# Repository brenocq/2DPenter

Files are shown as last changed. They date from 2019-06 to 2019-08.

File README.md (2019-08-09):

# 2D Penter
_by Breno Queiroz and Dikson Ferreira_

<p align="center">
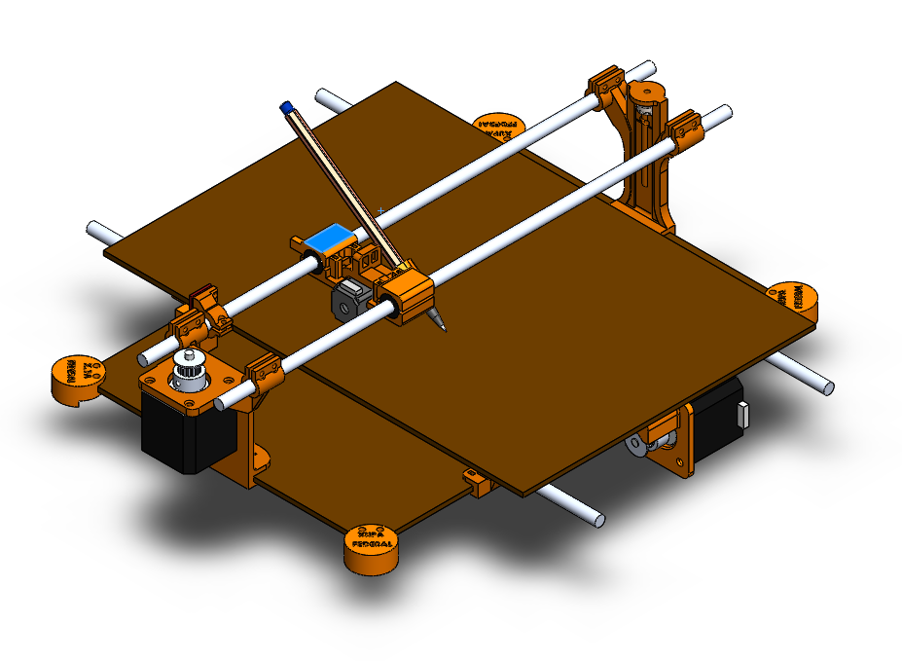
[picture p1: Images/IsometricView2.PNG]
 
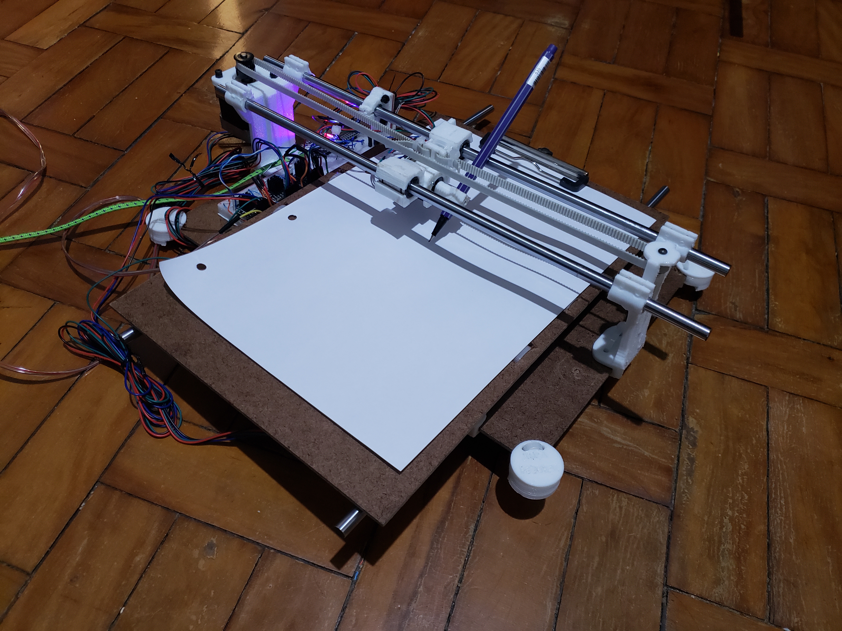
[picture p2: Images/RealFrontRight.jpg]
 
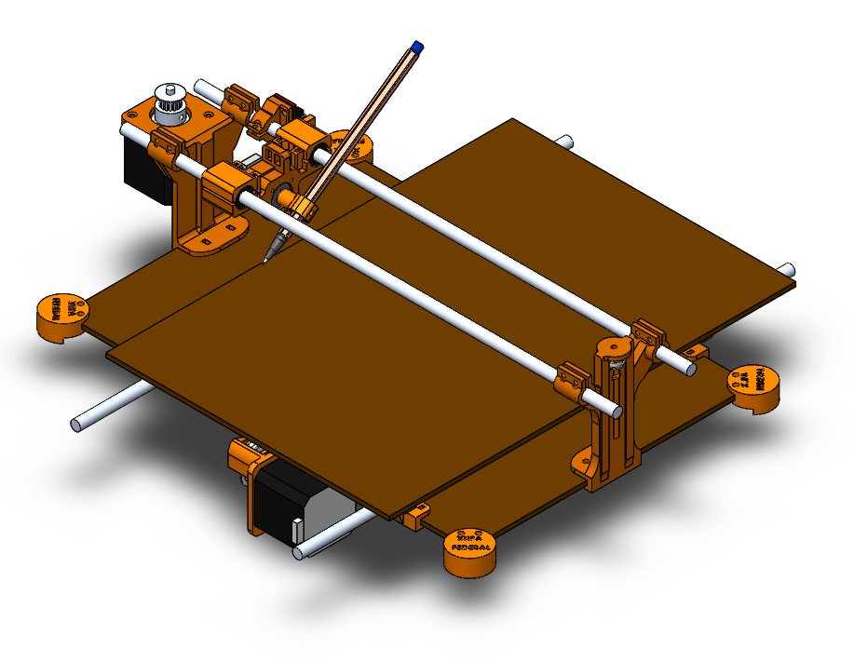
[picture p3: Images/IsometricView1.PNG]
 
</p>

## Introduction
This printer was designed to draw polynomial functions from a string. When connecting to the wifi network created by ESP32, it is possible to make the printer go home, move the axes, draw points on the paper, or send the polynomial function string to draw the graphic.

## Materials used
 - (2) Nema17 stepper motors
 - (1) Nema8 stepper motor
 - (3) Stepper Motor Driver
 - (2) GT2 Pulley 20T
 - (1) Esp32 DOIT
 - (2) Mechanical Endstop
 - (2) Clipboards
 - (1) GT2 Belt 6mm 3 meters
 - (1) PLA filament 0.25kg
 - (1) Stabilo Pen (can be another one of the same size)
 - (6) LM8UU bearing
 - (8) F623ZZ flange

## Building
All 3d modeled parts are available in the `3Dmodels` folder. First, open the `2Dprinter_v0.SLDASM` file using SolidWorks. After that, generate the STL file of each assembly part. Printed parts must have at least 50% of infill to ensure a sturdy structure.

#### Pen structure
<p align="center">
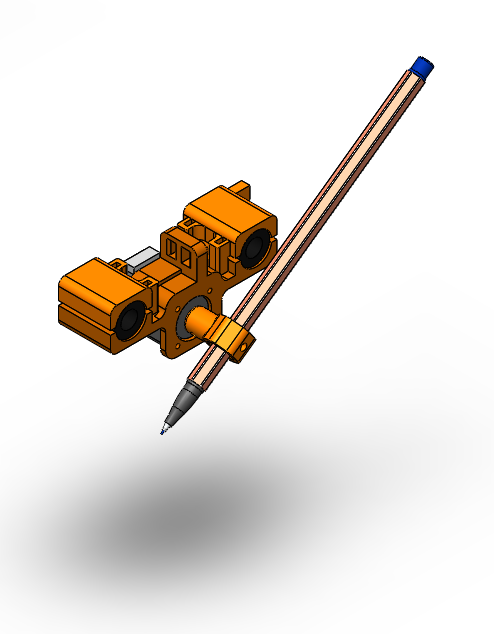
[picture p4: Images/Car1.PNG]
 
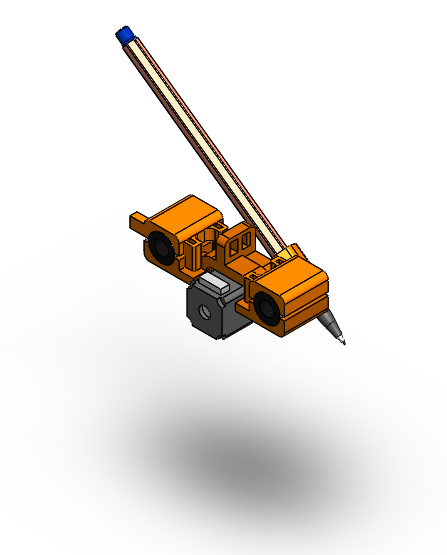
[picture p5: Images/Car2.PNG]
 
</p>

A Nema8 stepper motor was used to move the pen up and down.

#### Motor X
<p align="center">
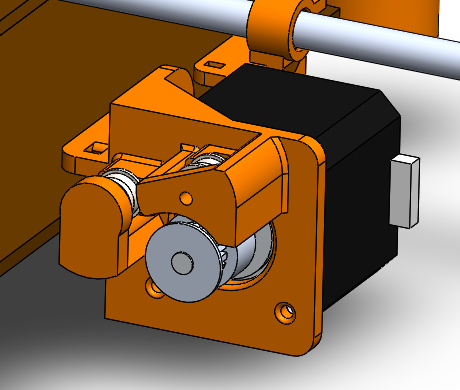
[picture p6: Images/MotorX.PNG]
 
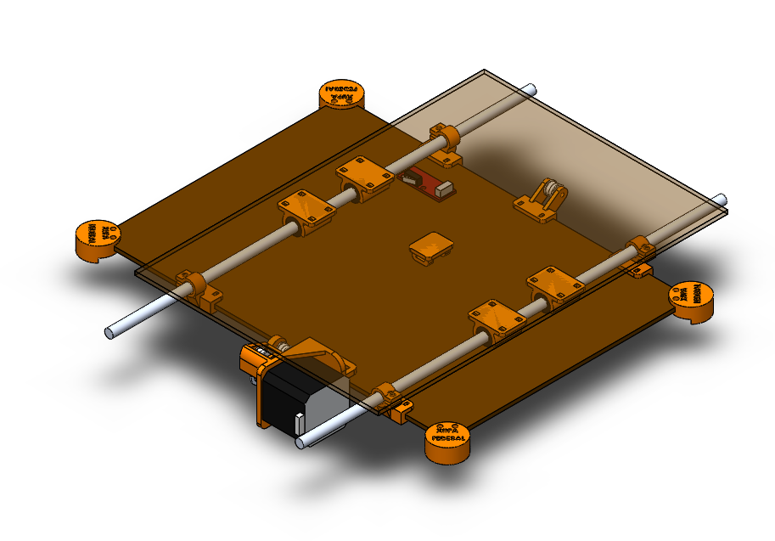
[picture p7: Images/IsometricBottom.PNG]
 
</p>

The image on the left shows motor X, this motor moves the bed to the left and right. There are 4 LM8UU bearing on the bottom of the bed as shown in the image on the right. An endstop button was used to set the minimum X.

#### Motor Y
<p align="center">
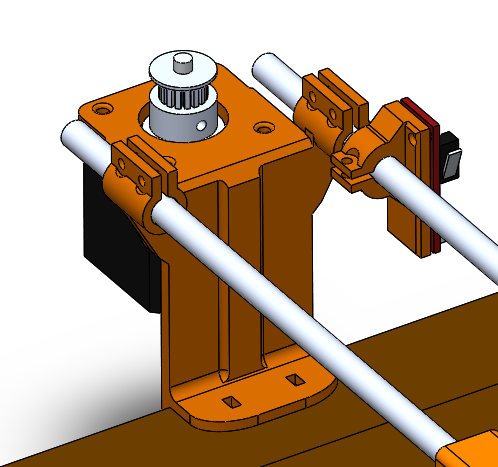
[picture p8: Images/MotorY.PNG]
  
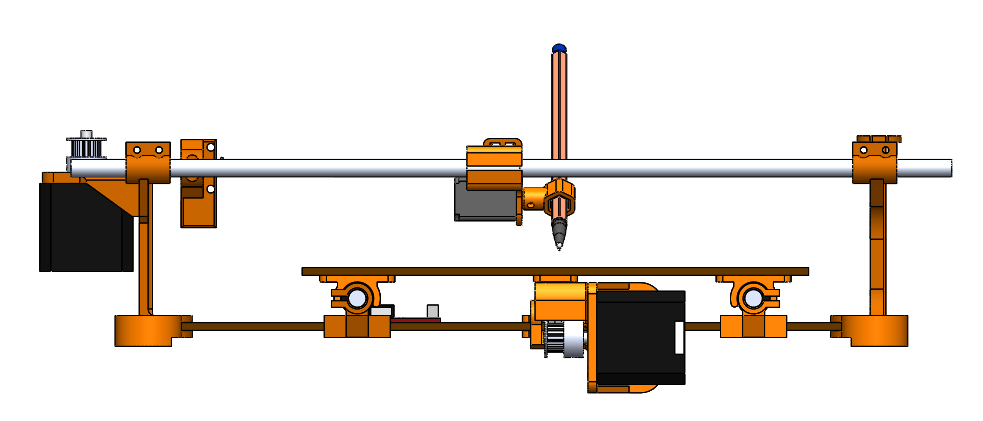
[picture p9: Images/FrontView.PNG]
  
</p>

The image above shows the motor Y, this motor moves the pen up and down. There is also an endstop button on the Y axis to detect the minimum Y.

#### Electronic
TODO

## How to use
Before going on, you must have Atom installed on your computer with the PlatformIO package installed on it.
#### Connecting to the ESP32
After turn on the printer, the ESP32 will try to connect to an WIFI network. Because of this, you need to change the code in `src/PlatformIO/src/main.cpp` before using the 2D Penter to set your WIFI network. First, Open the folder PlatformIO with Atom. After that, go to the line 9 and change _BrenoCQ_ to your wifi name. Also, go to the line 10 and change _penter2d_ to your WIFI password.

Now the 2D Penter will automatically connect to the WIFI and show its address on the Serial Monitor! _For example: 192.168.43.204_.

The only thing you need to do now is type this address on your browser and the website will appear.

#### Website

<p align="center">
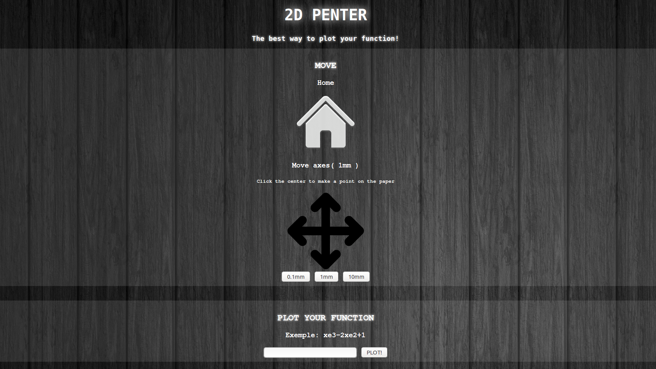
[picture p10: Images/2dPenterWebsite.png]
  
</p>
On this website there are some basic commands you can do with the 2D Penter.

The first command is **go home**, to do this just click on the house.

Just below this there are arrow where you can **move the axes**. You can set the distance that will be traveled by selecting 0.1mm, 1mm, or 10mm. If you click on the middle of the arrows the printer will make a point on the paper.

The last command is to **draw a polynomial functions**. After clicking `PLOT!` the printer will move home and begin drawing the function at the range (-2,2) on the X and Y axes.

## Results

<p align="center">
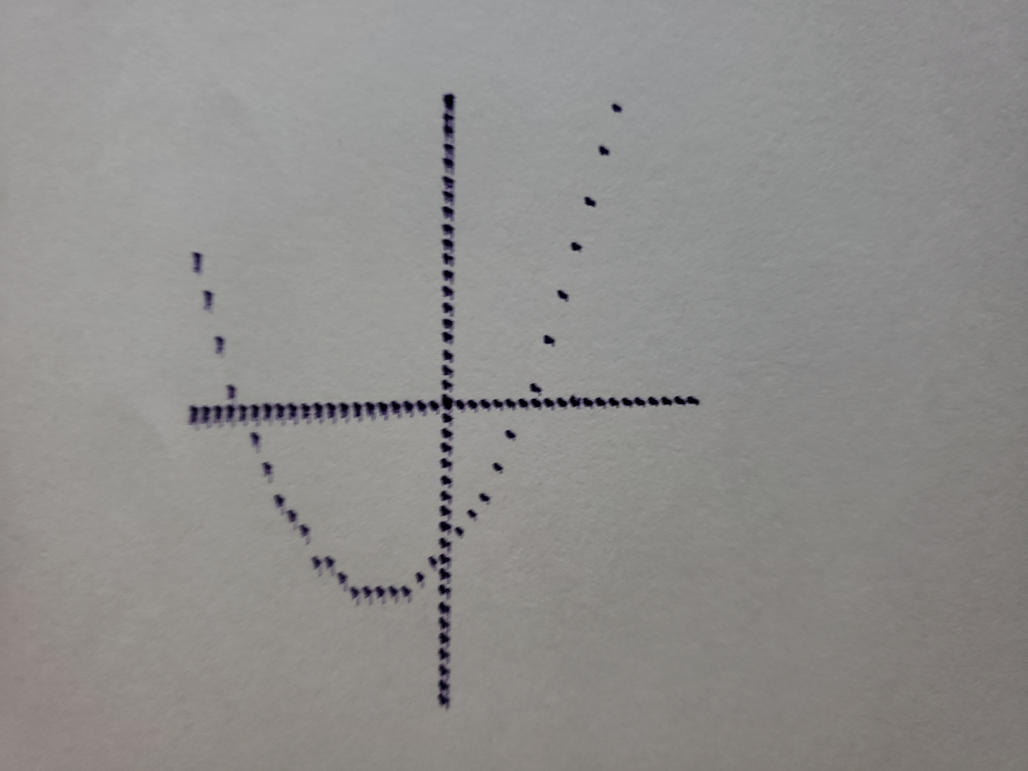
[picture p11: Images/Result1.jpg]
 
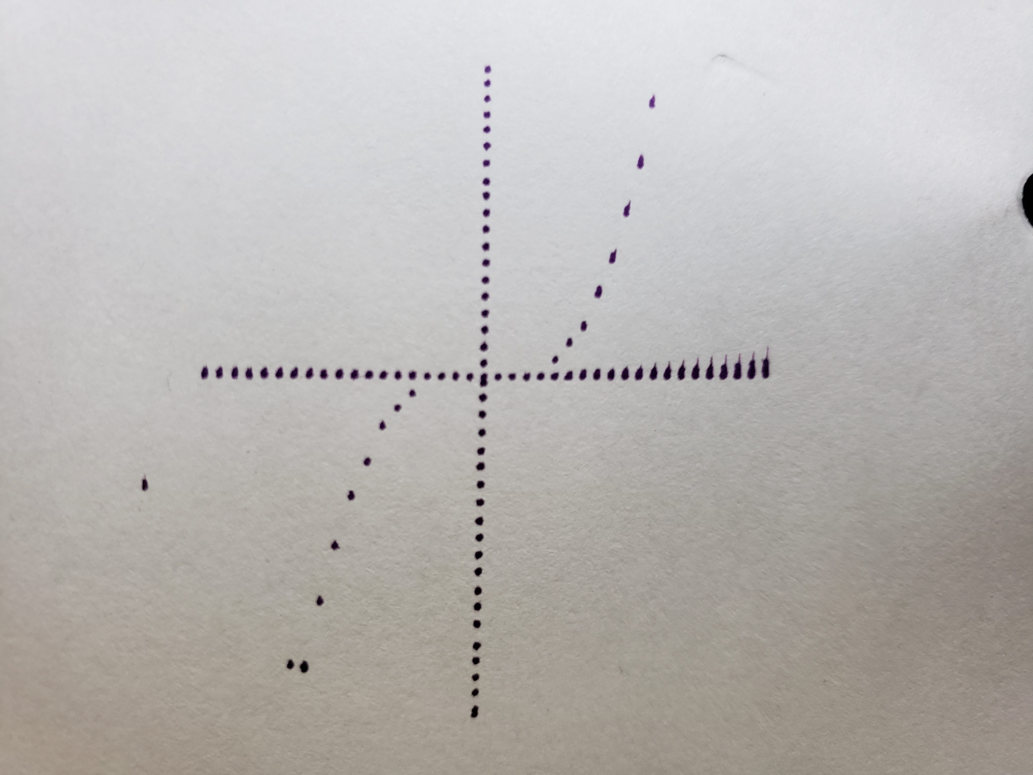
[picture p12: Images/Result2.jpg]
 
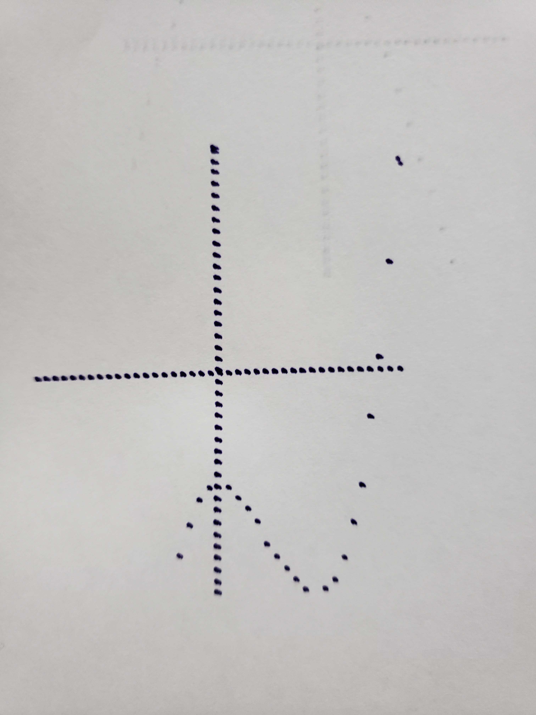
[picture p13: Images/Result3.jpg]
 
</p>
In the images above, we show some of the functions drawn by 2D Penter (the last one was rotated).

**Click [here](https://www.youtube.com/watch?v=S_lHMZDLUfM) to see the Youtube video.**

## Future Work
- Drawing the PCB wires in a copper plate to create circuits

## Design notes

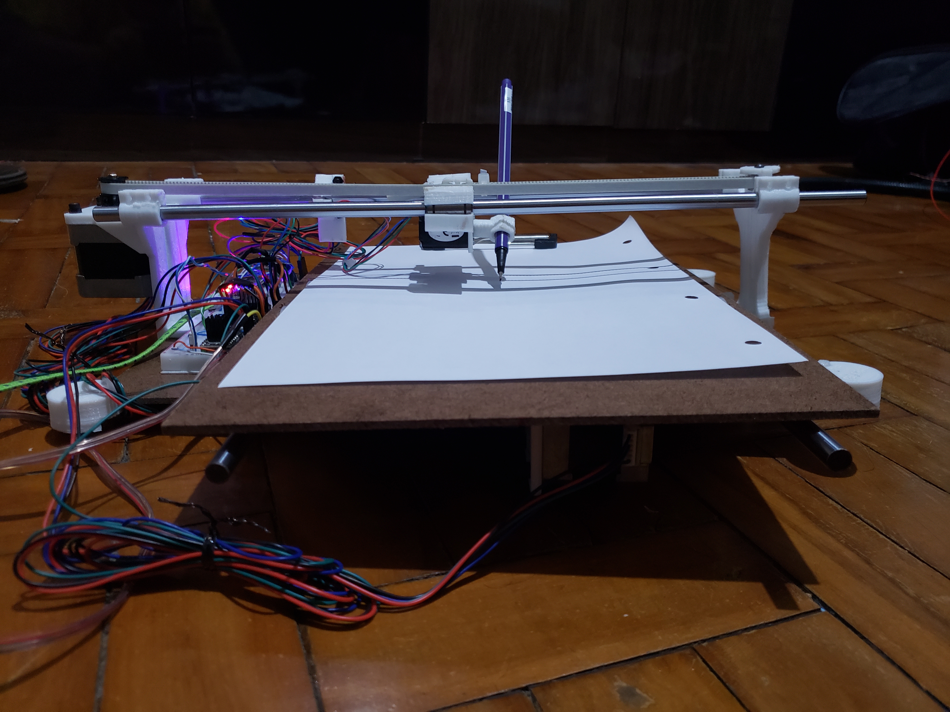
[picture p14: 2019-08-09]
Images/RealFront.jpg

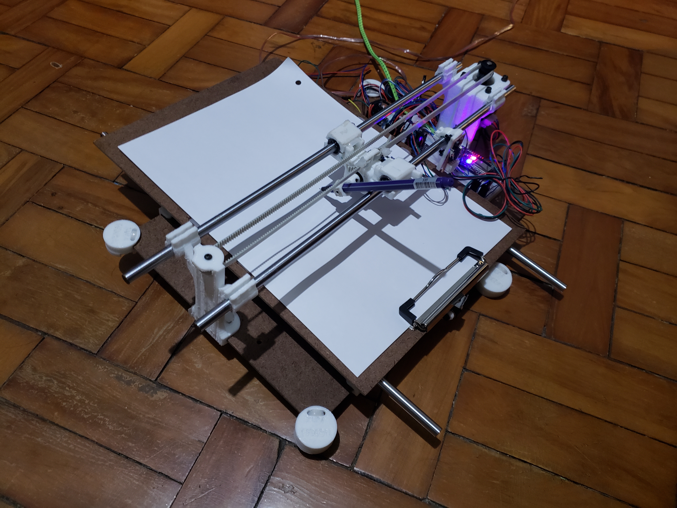
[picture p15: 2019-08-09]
Images/RealBackRight.jpg

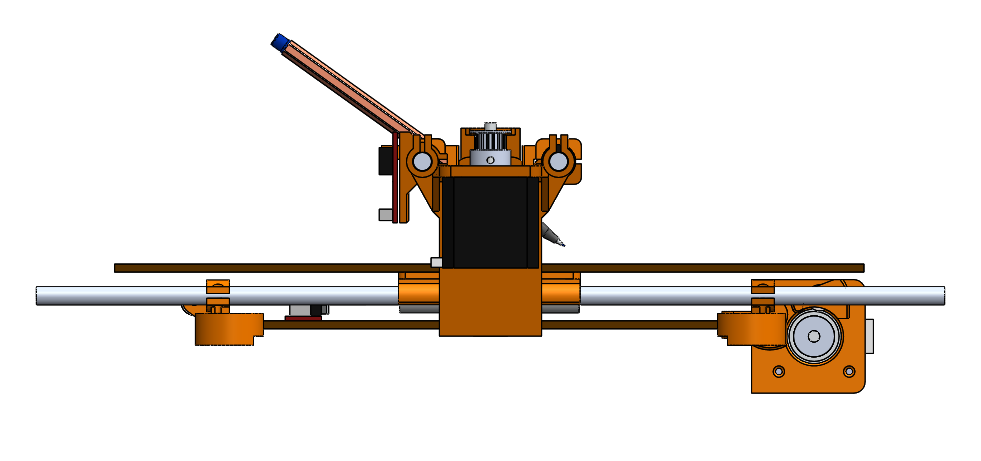
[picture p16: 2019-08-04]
Images/SideView.PNG

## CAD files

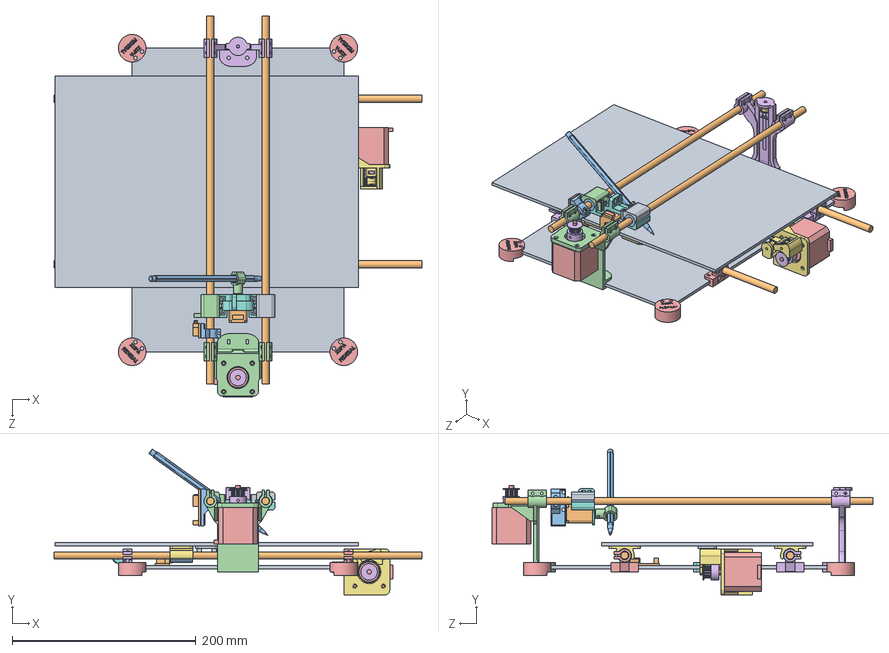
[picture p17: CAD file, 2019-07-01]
3Dmodels/2Dprinter_v0.SLDASM
400.0 x 158.4 x 414.1 mm
bed x 2
Barra lisa 8x400 x 4
Rolamento LM8UU x 6
SupYmotor
Feet x 4
SupYPulley
F623ZZ Flange x 8
Car
SupRolamento
Nema8Motor
Pen
SupPen
SupAxisX1 x 2
SupAxisX2 x 2
SupBearingX x 4
SupXPulley
FixBeltX
EndStop x 2
Suporte_endstop
SupPulleyEnd
Motor Nema17 (17HS4401) x 2
Polia dentada 20 GT2 x 2
SupXMotorNema17

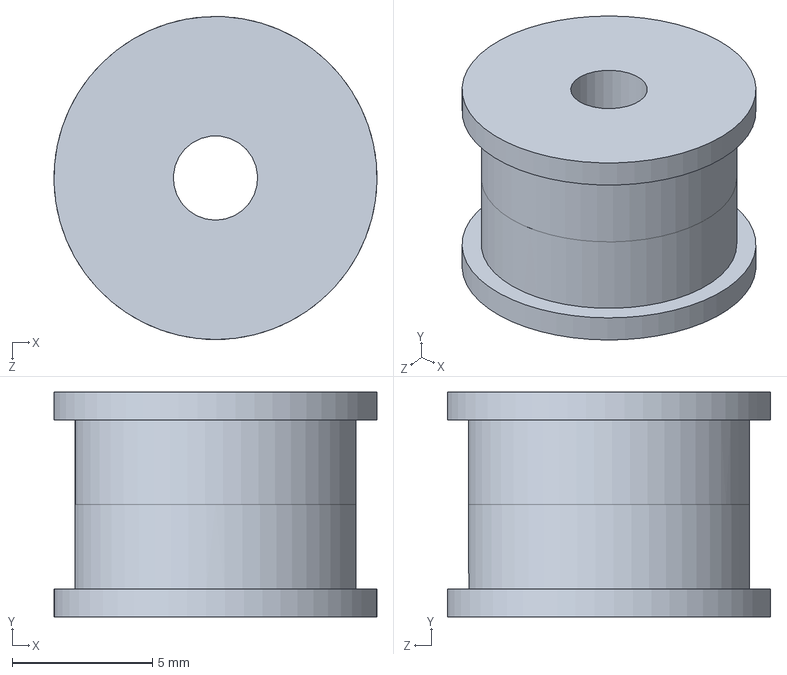
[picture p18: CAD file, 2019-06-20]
3Dmodels/Dois_flanges.SLDASM
11.5 x 8.00 x 11.5 mm
F623ZZ Flange x 2

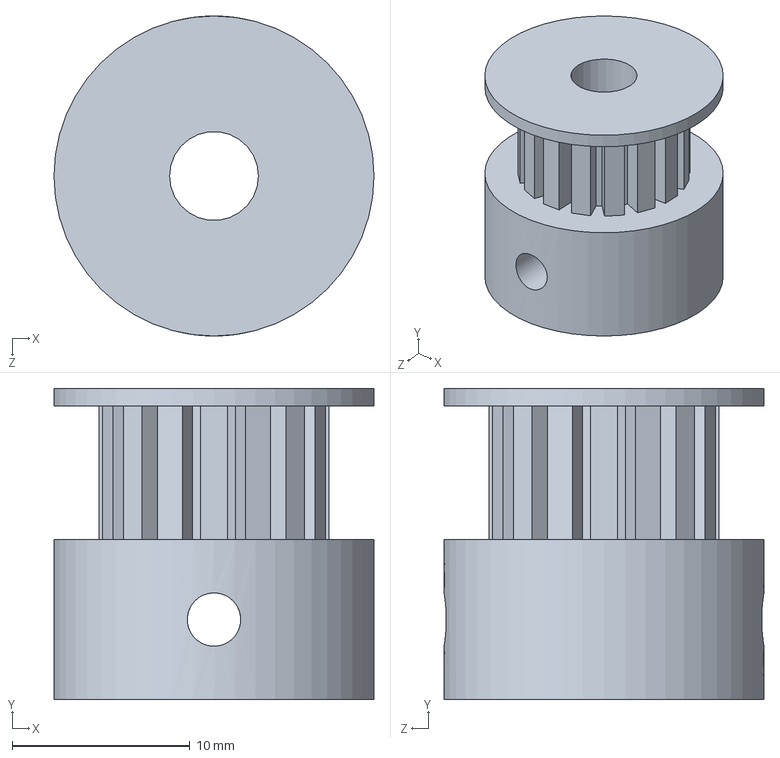
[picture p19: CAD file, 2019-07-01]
3Dmodels/Polia dentada 20 GT2.SLDPRT
18.0 x 17.5 x 18.0 mm

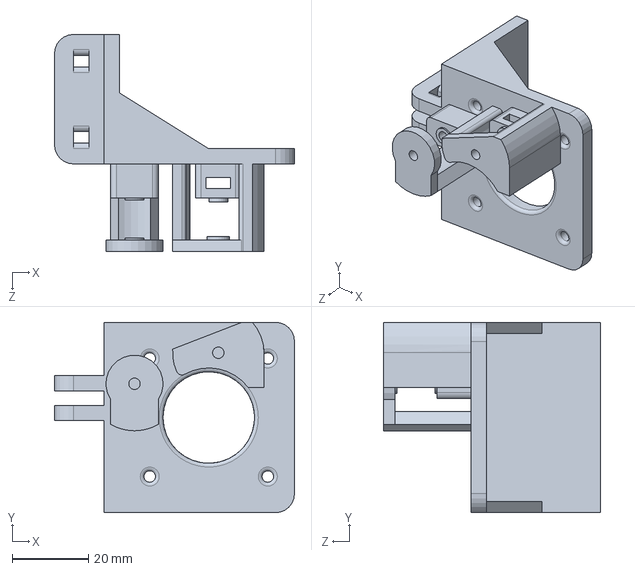
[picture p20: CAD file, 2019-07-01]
3Dmodels/SupXMotorNema17.SLDPRT
63.0 x 50.0 x 57.0 mm

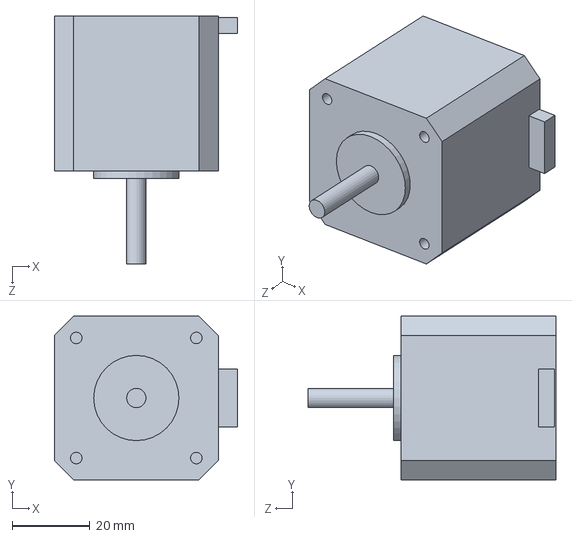
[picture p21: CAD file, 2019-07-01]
3Dmodels/Motor Nema17 (17HS4401).SLDPRT
47.3 x 42.3 x 64.0 mm

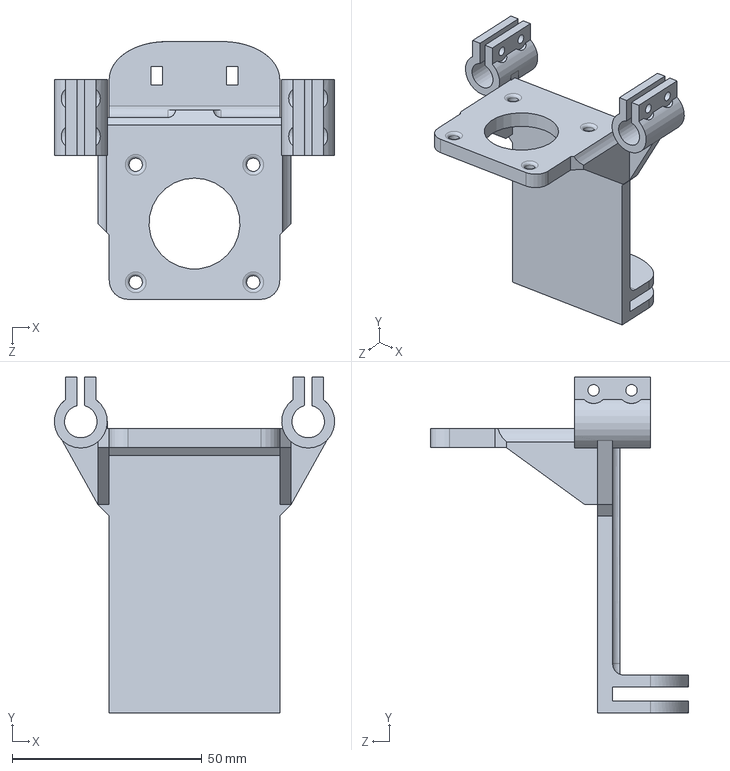
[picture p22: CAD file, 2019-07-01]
3Dmodels/SupYmotor.SLDPRT
74.0 x 88.6 x 68.0 mm

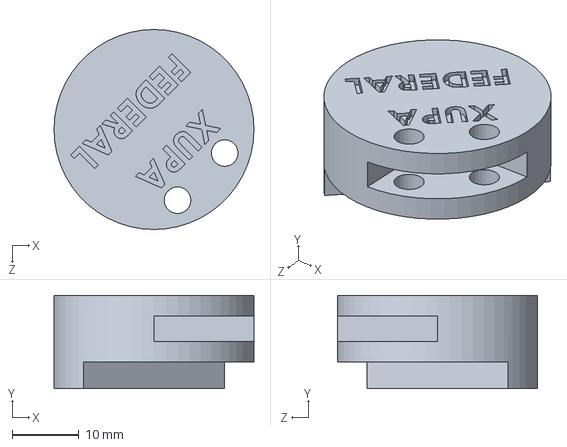
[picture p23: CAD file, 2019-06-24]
3Dmodels/Feet.SLDPRT
30.0 x 14.0 x 30.0 mm

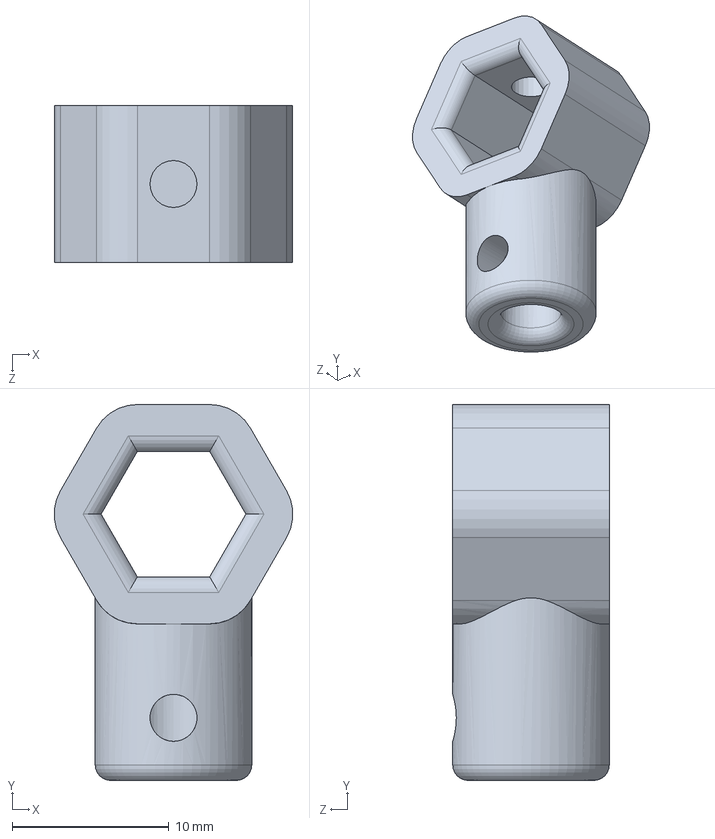
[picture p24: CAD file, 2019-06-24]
3Dmodels/SupPen.SLDPRT
15.2 x 24.0 x 10.0 mm

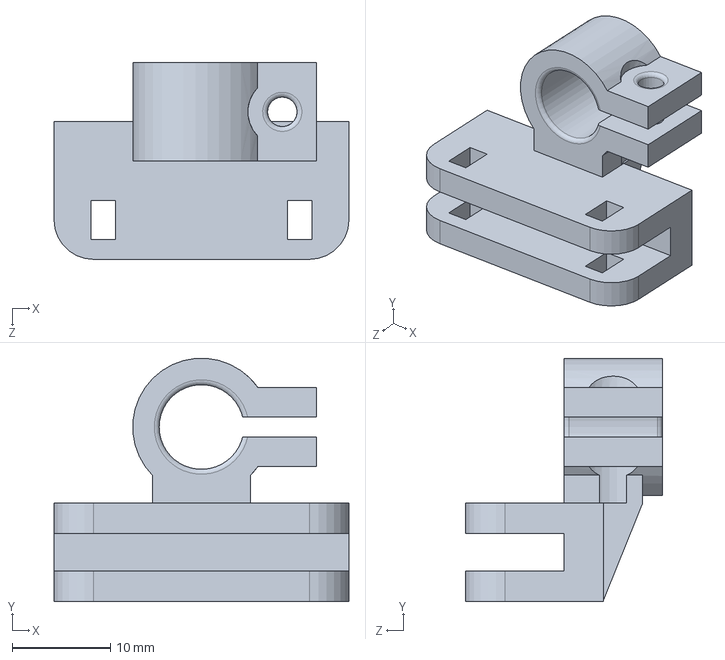
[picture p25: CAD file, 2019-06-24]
3Dmodels/SupAxisX1.SLDPRT
30.0 x 24.7 x 20.0 mm

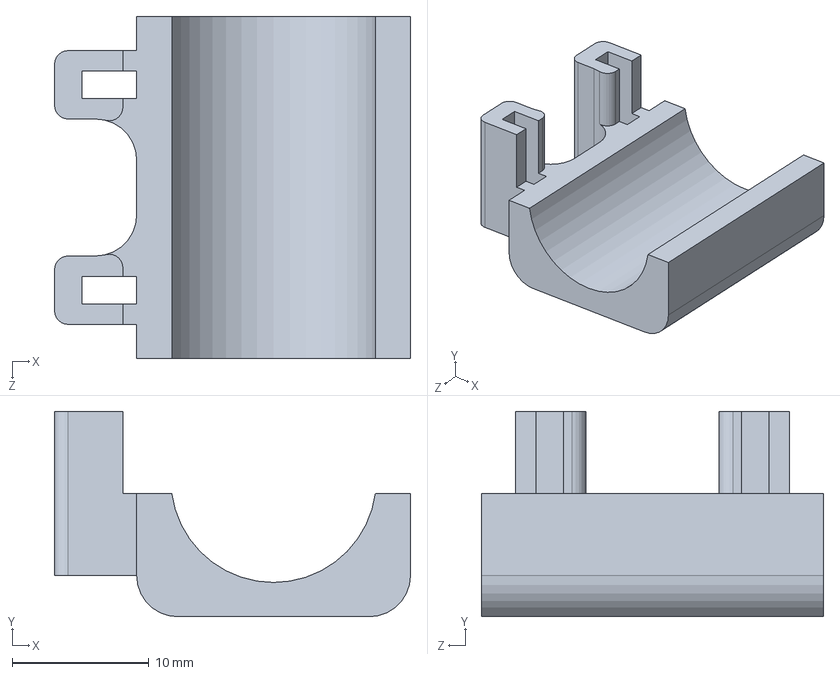
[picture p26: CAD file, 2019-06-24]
3Dmodels/SupRolamento.SLDPRT
26.0 x 15.0 x 25.0 mm

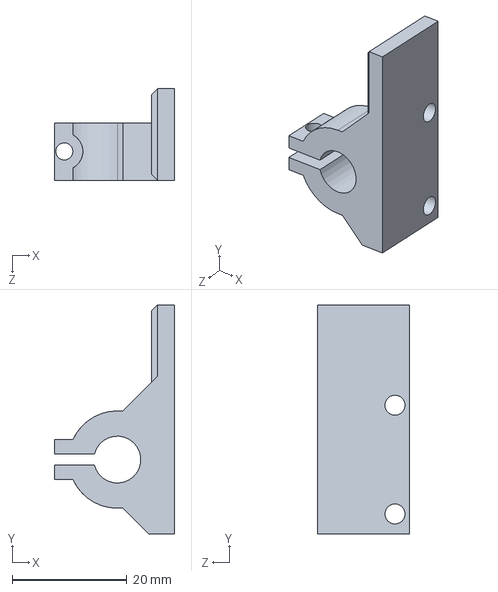
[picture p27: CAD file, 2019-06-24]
3Dmodels/SupEndstop.SLDPRT
21.0 x 40.0 x 16.0 mm

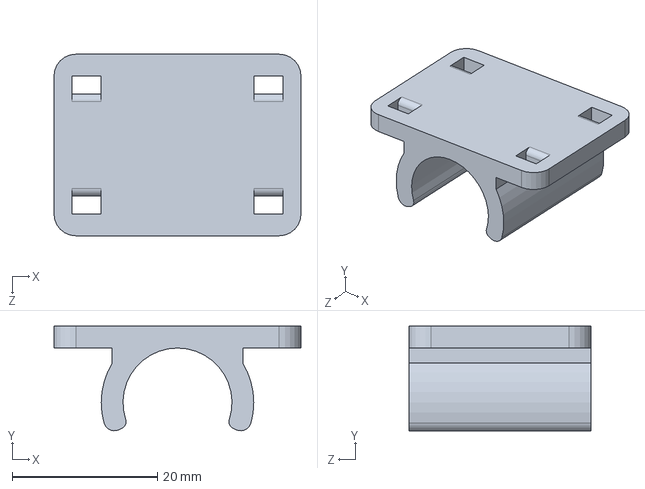
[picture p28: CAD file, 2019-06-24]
3Dmodels/SupBearingX.SLDPRT
34.0 x 14.4 x 25.0 mm

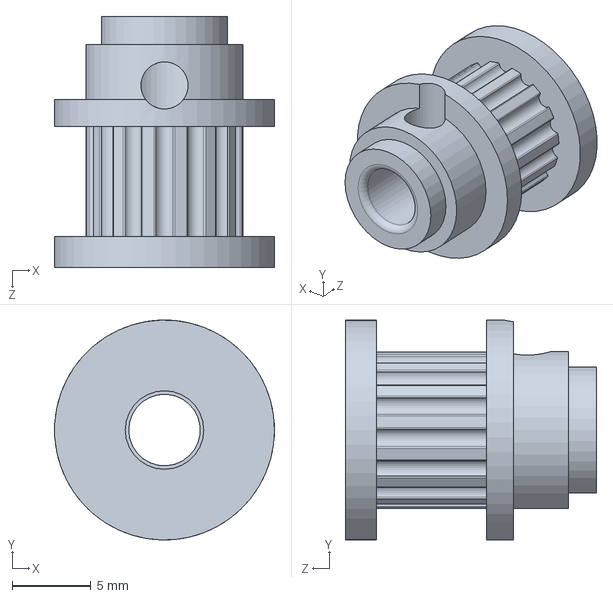
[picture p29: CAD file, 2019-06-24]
3Dmodels/GearMotor.SLDPRT
14.0 x 14.0 x 16.0 mm

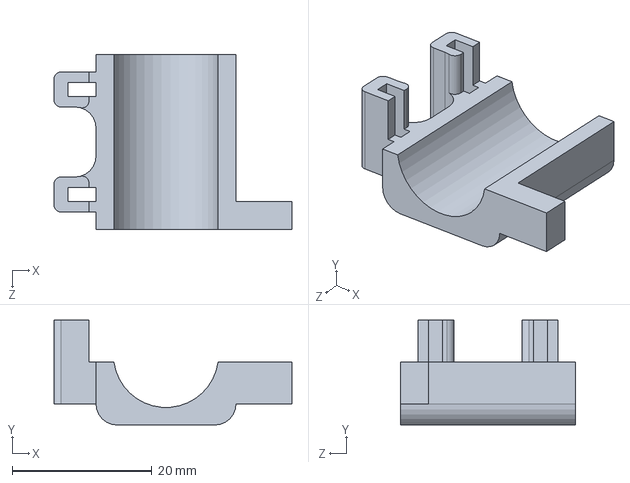
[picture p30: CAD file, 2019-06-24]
3Dmodels/SupPulleyEnd.SLDPRT
34.0 x 15.0 x 25.0 mm

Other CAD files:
3Dmodels/Suporte_endstop.SLDPRT
3Dmodels/SupAxisX2.SLDPRT
3Dmodels/Nema8Motor.SLDPRT
3Dmodels/F623ZZ Flange.SLDPRT
3Dmodels/Barra lisa 8x400.SLDPRT
3Dmodels/Car.SLDPRT
3Dmodels/ESP32.SLDPRT
3Dmodels/EndStop.SLDPRT
3Dmodels/FixBeltX.SLDPRT
3Dmodels/Pen.SLDPRT
3Dmodels/Rolamento LM8UU.SLDPRT
3Dmodels/STL/Feet.STL
3Dmodels/STL/FixBeltX.STL
3Dmodels/STL/GearMotor.STL
3Dmodels/STL/SupAxisX1.STL
3Dmodels/STL/SupAxisX2.STL
3Dmodels/STL/SupBearingX.STL
3Dmodels/STL/SupPen.STL
3Dmodels/STL/SupRolamento.STL
3Dmodels/STL/SupXPulley.STL
3Dmodels/SupXMotor.SLDPRT
3Dmodels/SupXPulley.SLDPRT
3Dmodels/SupYPulley.SLDPRT
3Dmodels/bed.SLDPRT

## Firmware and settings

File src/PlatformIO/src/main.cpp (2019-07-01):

#include <Arduino.h>
#include "penterSoftware.h"
#include <string>
#include <WiFi.h>
using namespace std;
#define SIZE 40

// Replace with your network credentials
const char* ssid     = "BrenoCQ";
const char* password = "penter2d";

// Set web server port number to 80
WiFiServer server(80);

// Variable to store the HTTP request
String header;

float moveDistance = 1;

float pot(float x, int k);
float mod(float k);
float f(string s, float x);
int num(string s, int l, int r);
void graph(bool a[SIZE][SIZE], string s, float prop);
void cross(bool a[SIZE][SIZE]);
void seta(bool a[SIZE][SIZE]);
void chama (bool a[SIZE][SIZE]);
void desenha(float x, float y);

PenterSoftware penter;
void setup() {
  Serial.begin(115200);
  penter.begin();

  // Connect to Wi-Fi network with SSID and password
  Serial.print("Connecting to ");
  Serial.println(ssid);
  WiFi.begin(ssid, password);
  while (WiFi.status() != WL_CONNECTED) {
    delay(500);
    Serial.print(".");
  }
  // Print local IP address and start web server
  Serial.println("");
  Serial.println("WiFi connected.");
  Serial.println("IP address: ");
  Serial.println(WiFi.localIP());
  server.begin();

}

void loop() {
  WiFiClient client = server.available();   // Listen for incoming clients
  if (client) {                             // If a new client connects,
    Serial.println("New Client.");          // print a message out in the serial port
    string currentLine = "";                // make a string to hofloat incoming data from the client
    while (client.connected()) {            // loop while the client's connected
      if (client.available()) {             // if there's bytes to read from the client,
        char c = client.read();             // read a byte, then
        Serial.write(c);                    // print it out the serial monitor
        header += c;
        if (c == '\n') {                    // if the byte is a newline character
          // if the current line is blank, you got two newline characters in a row.
          // that's the end of the client HTTP request, so send a response:
          if (currentLine.length() == 0) {
            // HTTP headers always start with a response code (e.g. HTTP/1.1 200 OK)
            // and a content-type so the client knows what's coming, then a blank line:
            client.println("HTTP/1.1 200 OK");
            client.println("Content-type:text/html");
            client.println("Connection: close");
            client.println();

            // turns the GPIOs on and off
            if (header.indexOf("GET /home") >= 0) {
              Serial.println("Ypositive");
              penter.moveHome();
            } else if (header.indexOf("GET /Ypositive") >= 0) {
              Serial.println("Ypositive");
              penter.moveAxes(0,moveDistance);
            } else if (header.indexOf("GET /Ynegative") >= 0) {
              Serial.println("Ynegative");
              penter.moveAxes(0,-moveDistance);
            } else if (header.indexOf("GET /Xpositive") >= 0) {
              Serial.println("Xpositive");
              penter.moveAxes(moveDistance,0);
            } else if (header.indexOf("GET /Xnegative") >= 0) {
              Serial.println("Xnegative");
              penter.moveAxes(-moveDistance,0);
            } else if (header.indexOf("GET /Point") >= 0) {
              penter.penPoint();
            } else if (header.indexOf("GET /001") >= 0) {
              moveDistance = 0.1;
            } else if (header.indexOf("GET /010") >= 0) {
              moveDistance = 1;
            } else if (header.indexOf("GET /100") >= 0) {
              moveDistance = 10;
            } else if (header.indexOf("GET /Plot") >= 0) {
              string function="";
              int indexIni = header.indexOf("GET /Plot")+9;
              int indexEnd = header.indexOf(" HTTP");
              for (size_t i = indexIni; i < indexEnd; i++) {
                function+=header[i];
              }
              //Serial.print("FUNCTION:");Serial.println(function);
              //function = "xe2-1";
              // Move penter to home
              penter.moveHome();
              bool matrix[SIZE][SIZE];
              for (int i = 0; i < SIZE; i++) {
                for (int j = 0; j < SIZE; j++) {
                  matrix[i][j] = 0;
                }
              }
              float zoom=2;
              zoom=(SIZE/2)/zoom;
              seta (matrix);
              graph(matrix, function, zoom);
              for (int i = 0; i < SIZE; i++) {
                for (int j = 0; j < SIZE; j++) {
                  Serial.print(matrix[i][j]);Serial.print(" ");
                }
                Serial.println();
              }
              chama(matrix);
              //cross(matrix);
              //graph(matrix, str, zoom);
            }

            client.println("<!DOCTYPE html>");
            client.println("<html lang=\"en\">");
            client.println("<head>");
            client.println("  <!-- Style CSS -->");
            client.println("  <style>");
            client.println("    h1{");
            client.println("      font-size: 30pt;");
            client.println("      color: white;");
            client.println("      text-shadow: 0px 0px 20px white;");
            client.println("      text-align: center;");
            client.println("    }");
            client.println("    h2{");
            client.println("      color: white;");
            client.println("      text-align: center;");
            client.println("      text-shadow: 0px 0px 5px white;");
            client.println("    }");
            client.println("    body{");
            client.println("      background-image: url(http://wallpoper.com/images/00/31/33/51/black-background_00313351.jpg);");
            client.println("      color: white;");
            client.println("      font-family: Courier;");
            client.println("    }");
            client.println("    .plotFunc, .move{");
            client.println("      background-color: rgba(255,255,255,.1);");
            client.println("      text-align: center;");
            client.println("      padding-top: 10px;");
            client.println("      padding-bottom: 10px;");
            client.println("      margin: 0px 0px 0px 0px;");
            client.println("      border: 0px;");
            client.println("    }");
            client.println("    .column {");
            client.println("      float: left;");
            client.println("      width: 50%%;");
            client.println("    }");
            client.println("");
            client.println("    /* Clear floats after the columns */");
            client.println("    .row:after {");
            client.println("      content: \"\";");
            client.println("      display: table;");
            client.println("      clear: both;");
            client.println("    }");
            client.println("");
            client.println("  </style>");
            client.println("  <!-- Script JavaScript -->");
            client.println("");
            client.println("  <script>");
            client.println("");
            client.println("  </script>");
            client.println("</head>");
            client.println("<body>");
            client.println("");
            client.println("  <header>");
            client.println("    <title> 2D Pentel </title>");
            client.println("    <code>");
            client.println("    <h1>2D <b>PEN</b>TER</h1>");
            client.println("    <h2><code>The best way to plot your function!</code></h2>");
            client.println("    </code>");
            client.println("  </header>");
            client.println("");
            client.println("  <div class=\"interface\">");
            client.println("");
            client.println("    <div class=\"move\">");
            client.println("      <h2>MOVE</h2>");
            client.println("      <div class=\"row\">");
            client.println("          <h3>Home</h3>");
            client.println("            <a href=\"/home\"><img src=\"http://www.newdesignfile.com/postpic/2010/03/home-icon-white_338306.png\" height=\"150\" /></a>");
            client.println("          <center>");
            client.print("             <h3>Move axes( ");client.print(moveDistance);client.println("mm )</h3>");
            client.println("             <h5>Click the center to make a point on the paper</h5>");
            client.println("             <img src=\"https://image.flaticon.com/icons/svg/60/60931.svg\" alt = \"arrows\" usemap = \"#arrowMap\" height=\"200\">");
            client.println("           </center>");
            client.println("           <map name = \"arrowMap\">");
            client.println("             <area shape = \"rect\" coords = \"50,0,150,60\" alt = \"up arrow\"");
            client.println("               href = \"/Ypositive\" target = \"_blank\" />");
            client.println("             <area shape = \"rect\" coords = \"50,140,150,200\" alt = \"down arrow\"");
            client.println("                href = \"/Ynegative\" target = \"_blank\" />");
            client.println("             <area shape = \"rect\" coords = \"140,50,200,150\" alt = \"right arrow\"");
            client.println("               href = \"/Xpositive\" target = \"_blank\" />");
            client.println("             <area shape = \"rect\" coords = \"0,50,60,150\" alt = \"left arrow\"");
            client.println("               href = \"/Xnegative\" target = \"_blank\" />");
            client.println("             <area shape = \"rect\" coords = \"60,60,140,140\" alt = \"central\"");
            client.println("               href = \"/Point\" target = \"_blank\" />");
            client.println("           </map>");
            client.println("           <input type=\"button\" value=\"0.1mm\" onclick=\"window.location.href = \'/001\';\"/>");
            client.println("           <input type=\"button\" value=\"1mm\"   onclick=\"window.location.href = \'/010\';\"/>");
            client.println("           <input type=\"button\" value=\"10mm\"   onclick=\"window.location.href = \'/100\';\"/>");
            client.println("      </div>");
            client.println("    </div>");
            client.println("");
            client.println("    <br /><br />");
            client.println("");
            client.println("    <div class=\"plotFunc\">");
            client.println("      <h2>PLOT YOUR FUNCTION</h2>");
            client.println("      <h3>Exemple: xe3-2xe2+1</h3>");
            client.println("      <div>");
            client.println("         <input type = \"text\" id = \"inputText\"></input>");
            client.println("         <button onClick=\"javascript: window.open(\'/Plot\' + document.getElementById(\'inputText\').value);\" id = \"sendButton\">PLOT!</button>");
            client.println("      </div>");
            client.println("    </div>");
            client.println("");
            client.println("  </div>");
            client.println("</body>");
            client.println("</html>");
            client.println();

            break;
          } else { // if you got a newline, then clear currentLine
            currentLine = "";
          }
        } else if (c != '\r') {  // if you got anything else but a carriage return character,
          currentLine += c;      // add it to the end of the currentLine
        }
      }
    }
    // Clear the header variable
    header = "";
    // Close the connection
    client.stop();
    Serial.println("Client disconnected.");
    Serial.println("");
}
}

float mod(float k){
	if (k<0) k*=-1;
	return k;
}

float pot(float x, int k){
	if (k==0) return 1;
	else return pot(x, k-1)*x;
}

int num(string s, int l, int r){
	int a = 0, i;
	for (i=l; i<r; i++){
		a*=10;
		a+=s[i]-'0';
	}
	return a;
}

float f(string s, float x){
	float sum = 0;
	int a[100], i, l, r, m, coef, expoent, flag = 0;
	string aux;
	for (i=0; i<100; i++) a[i]=0;
	if (s[0]!='+' && s[0]!='-') {
		aux="+"+s;
		s=aux;
	}
	l=r=0;
	while(s[l]!='\0'){
		flag = 0;

		if (s[l+1]=='x') {
			coef = 1;
			m = l+1; //m indica a posição do x

		}
		else {
			for (i=l+1; i<=s.size(); i++){
				if (s[i]=='x'){
					coef = num(s, l+1, i); //função num retorna o numero contido entre a substring s[l+1, i]
					m = i;
					break;
				}
				if (s[i]=='\0' || s[i]=='+' || s[i]=='-'){
					if (s[l]=='+') a[0] += num(s, l+1, i);
					else a[0] -= num(s, l+1, i);
					flag = 1;
					r = i;
					l = r;
					break;
				}
			}
		}

		if (flag) continue;

		if (s[m+1]!='e') {
			expoent = 1;
			r = m+1;
		}
		else {
			for (i=m+2; i<=s.size(); i++){
				if (s[i]=='+' || s[i]=='-' || s[i]=='\0'){
					expoent = num(s, m+2, i);
					r = i;
					break;
				}
			}
		}
		if (s[l]=='+') a[expoent] += coef;
		else a[expoent] -= coef;
		l = r;
	}

	for (i=0; i<100; i++) sum += a[i]*pot(x, i);
	return sum;
}

void graph(bool a[SIZE][SIZE], string s, float prop){
	float x;
	float y;
	for (x=-(SIZE/2); x<SIZE/2; x++){
		y = prop*f(s, x/prop);
    Serial.print("f(");Serial.print(x);Serial.print("):");Serial.println(y);
		if (mod(y)<SIZE/2) a[SIZE/2-(int)y][(int)x+SIZE/2]=0;
	}
	return;
}

void cross(bool a[SIZE][SIZE]){
	int i;
	for (i=0; i<SIZE; i++){
		a[SIZE/2][i]=0;
		a[i][SIZE/2]=0;
	}
}

void seta(bool a[SIZE][SIZE]){
	int i, j;
	for (i=0; i<SIZE; i++) for (j=0; j<SIZE; j++) a[i][j]=1;
}

void chama (bool a[SIZE][SIZE]){
	int i, j;
	for (i=0; i<SIZE; i++) desenha((float)i, SIZE/2);
	for (i=0; i<SIZE; i++) desenha(SIZE/2, (float)i);
	for (j=0; j<SIZE; j++){
		for (i=0; i<SIZE; i++){
			if (a[i][j]==0 && i != SIZE/2 && j != SIZE/2) desenha((float)i, (float)j);
		}
	}
}

void desenha(float x, float y){
	penter.point(x,y);
}

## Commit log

2019-06-20 Style: 3Dmodels folder
    [2Dprinter_v0.SLDASM, Barra lisa 8x400.SLDPRT, Car.SLDPRT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]
2019-06-20 Feat: Move stepper motor
    [Feet.STL, FixBeltX.STL, GearMotor.STL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]
2019-06-20 Feat: First 3D models
    [2Dprinter_v0.SLDASM, Barra lisa 8x400.SLDPRT, Car.SLDPRT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]
2019-06-20 Feat: STL files
    [Feet.STL, FixBeltX.STL, GearMotor.STL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]
2019-06-21 Feat: Convert html to arduino code
2019-06-22 Refeat: Changes in some dimensions
    [2Dprinter_v0.SLDASM, Feet.SLDPRT, GearMotor.SLDPRT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]
2019-06-24 Feat: Move motor with penter class
2019-06-27 Refeat: Changing models from Nema8 to Nema17
    It was necessary a motor with greater torque
    [2Dprinter_v0.SLDASM, Motor Nema17 (17HS4401).SLDPRT, Polia dentada 20 GT2.SLDPRT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]
2019-07-01 Feat: Control the printer through the site
2019-08-09 Docs: Physical printer images
